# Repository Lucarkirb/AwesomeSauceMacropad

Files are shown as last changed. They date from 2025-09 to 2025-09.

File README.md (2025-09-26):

# AWESOME SAUCE MACROPAD

The best worst macropad I have ever made, for the world to see. 
Runs custom firmware that will support almost infinite layers, macros, and maybe even AHK support?

## What the hell is it?
It's a Seeed studio xiao rp2040 macro pad designed like a madman, with custom firmware thats coming real soon. 
The layout is a 3x3 + an extra 3 button thumb cluster that lets you add more common keys like layer shifters or modifiers. It also has an encoder that can work as what you want but also allows you to interact with the firmwares settings, along with an OLED display to do your bidding.

Currently, the project is a mess as the thing requires the KY-040 encoder breakout board instead of just an smt encoder and also requires a generic i2c oled screen you get for your arduinos.

 

## Can I get it? 
Go order it yourself, tho pcba is going to get pricy since the neo pixels are costly to handle in a factory. Luckily they are super easy to hand solder.

Currently, the project is still being manufactured as im writing this, and thus i dont have any way to write firmware. Stay tuned.

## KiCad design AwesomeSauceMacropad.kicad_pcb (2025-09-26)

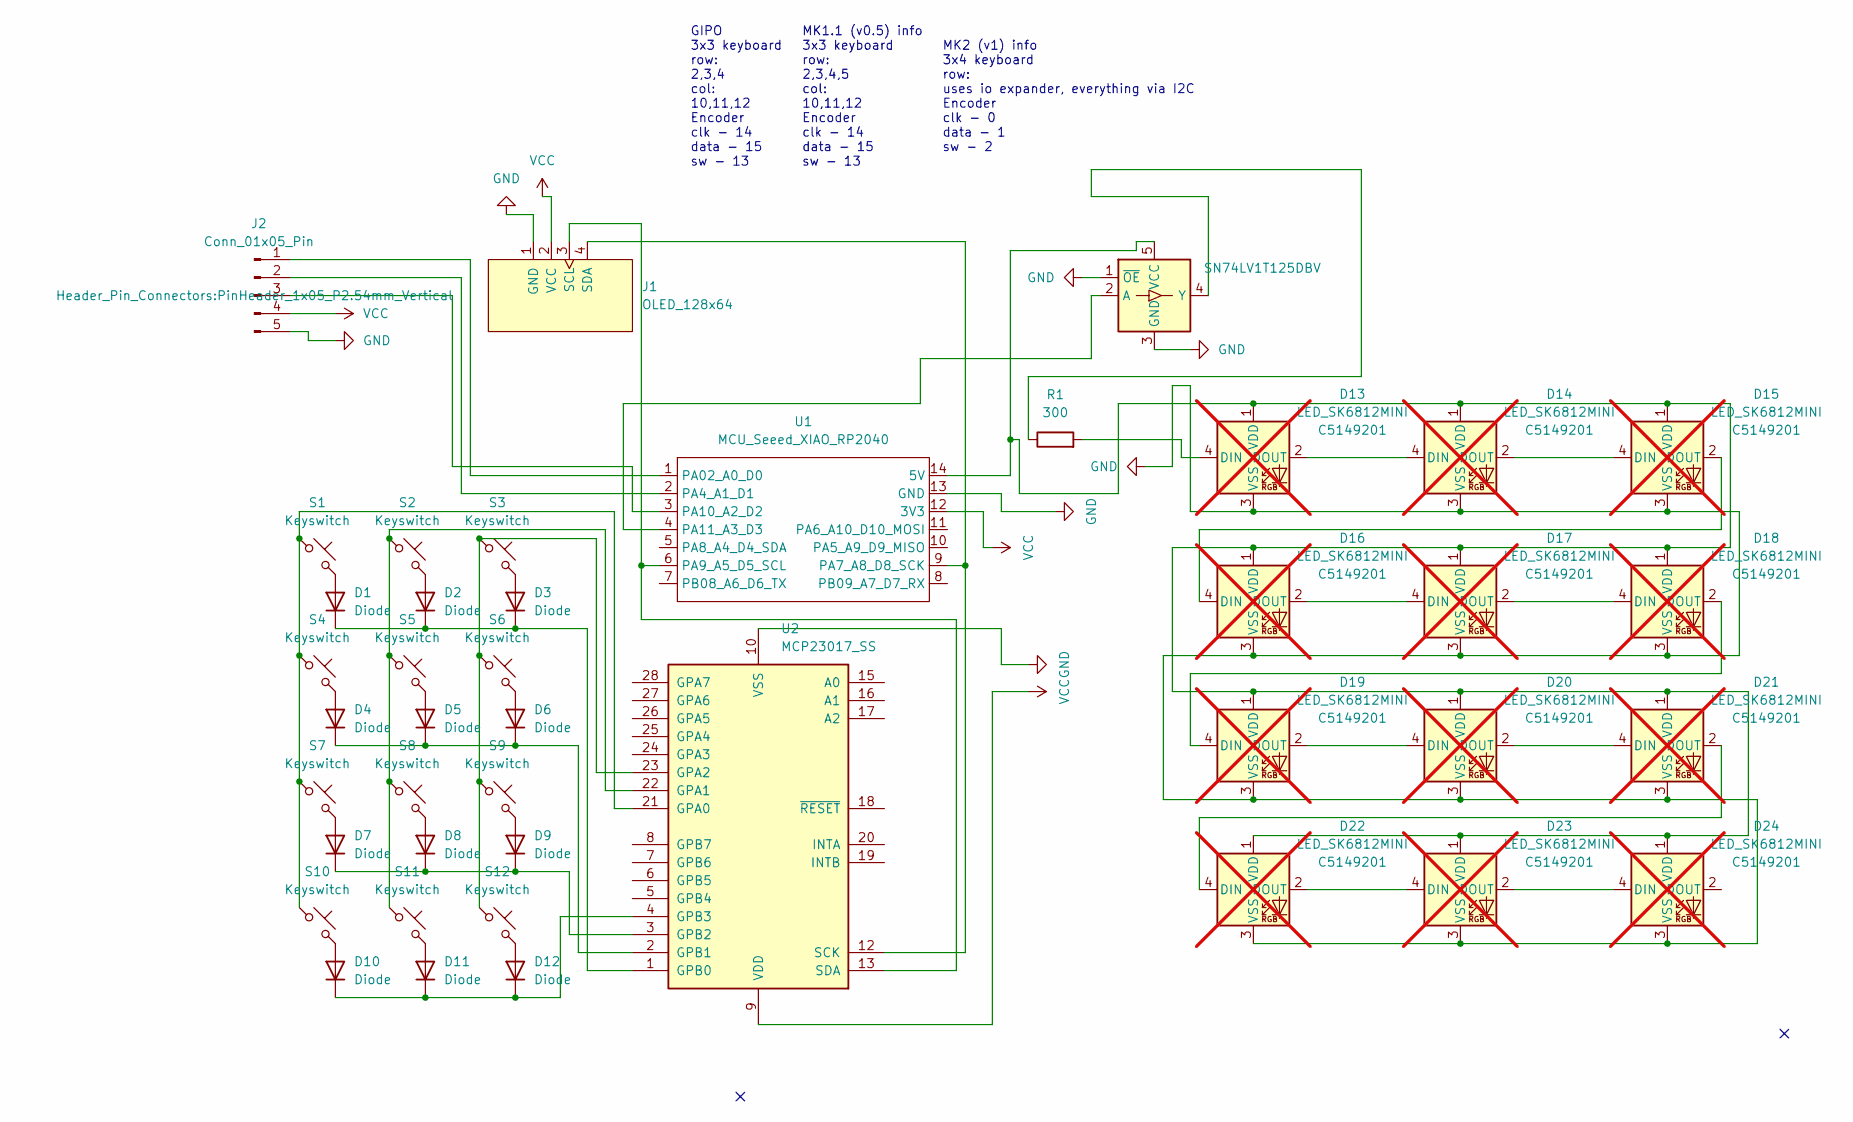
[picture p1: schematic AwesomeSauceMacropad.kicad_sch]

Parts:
D1, D2, D3, D4, D5, D6, D7, D8, D9, D10, D11, D12: Diode; Diode_SOD-123
D13, D14, D15, D16, D17, D18, D19, D20, D21, D22, D23, D24: LED_SK6812MINI; LCSC C5149201; not fitted
J1: OLED_128x64
J2: Conn_01x05_Pin; PinHeader_1x05_P2.54mm_Vertical
R1: 300; Resistor_0805
S1, S2, S3, S4, S5, S6, S7, S8, S9, S10, S11, S12: Keyswitch; Hotswap_Choc_V1V2_1.00u
U1: MCU_Seeed_XIAO_RP2040; Seeed_XIAO_RP2040
U2: MCP23017_SS; SSOP-28_5.3x10.2mm_P0.65mm
U3: SN74LV1T125DBV; SOT-23-5

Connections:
GND: D13.3 (VSS), D14.3 (VSS), D15.3 (VSS), D16.3 (VSS), D17.3 (VSS), D18.3 (VSS), D19.3 (VSS), D20.3 (VSS), D21.3 (VSS), D22.3 (VSS), D23.3 (VSS), D24.3 (VSS), J1.1 (GND), J2.5, U1.13 (GND), U2.10 (VSS), U3.1 (~OE), U3.3 (GND)
unnamed: D1.2 (A), S1.2
unnamed: D1.1 (K), D2.1 (K), D3.1 (K), U2.1 (GPB0)
unnamed: D2.2 (A), S2.2
unnamed: D3.2 (A), S3.2
unnamed: D4.2 (A), S4.2
unnamed: D4.1 (K), D5.1 (K), D6.1 (K), U2.2 (GPB1)
unnamed: D5.2 (A), S5.2
unnamed: D6.2 (A), S6.2
unnamed: D7.2 (A), S7.2
unnamed: D7.1 (K), D8.1 (K), D9.1 (K), U2.3 (GPB2)
unnamed: D8.2 (A), S8.2
unnamed: D9.2 (A), S9.2
unnamed: D10.2 (A), S10.2
unnamed: D10.1 (K), D11.1 (K), D12.1 (K), U2.4 (GPB3)
unnamed: D11.2 (A), S11.2
unnamed: D12.2 (A), S12.2
unnamed: D13.4 (DIN), R1.2
unnamed: D13.2 (DOUT), D14.4 (DIN)
unnamed: D13.1 (VDD), D14.1 (VDD), D15.1 (VDD), D16.1 (VDD), D17.1 (VDD), D18.1 (VDD), D19.1 (VDD), D20.1 (VDD), D21.1 (VDD), D22.1 (VDD), D23.1 (VDD), D24.1 (VDD), U1.14 (5V), U3.5 (VCC)
unnamed: D14.2 (DOUT), D15.4 (DIN)
unnamed: D15.2 (DOUT), D16.4 (DIN)
unnamed: D16.2 (DOUT), D17.4 (DIN)
unnamed: D17.2 (DOUT), D18.4 (DIN)
unnamed: D18.2 (DOUT), D19.4 (DIN)
unnamed: D19.2 (DOUT), D20.4 (DIN)
unnamed: D20.2 (DOUT), D21.4 (DIN)
unnamed: D21.2 (DOUT), D22.4 (DIN)
unnamed: D22.2 (DOUT), D23.4 (DIN)
unnamed: D23.2 (DOUT), D24.4 (DIN)
unnamed: J1.3 (SCL), U1.6 (PA9_A5_D5_SCL), U2.13 (SDA)
unnamed: J1.4 (SDA), U1.9 (PA7_A8_D8_SCK), U2.12 (SCK)
unnamed: J2.1, U1.1 (PA02_A0_D0)
unnamed: J2.2, U1.2 (PA4_A1_D1)
unnamed: J2.3, U1.3 (PA10_A2_D2)
unnamed: U1.4 (PA11_A3_D3), U3.2 (A)
unnamed: S1.1, S4.1, S7.1, S10.1, U2.21 (GPA0)
unnamed: S2.1, S5.1, S8.1, S11.1, U2.22 (GPA1)
unnamed: S3.1, S6.1, S9.1, S12.1, U2.23 (GPA2)
unnamed: R1.1, U3.4 (Y)
VCC: J1.2 (VCC), J2.4, U1.12 (3V3), U2.9 (VDD)

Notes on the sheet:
MK2 (v1) info 3x4 keyboard row: uses io expander, everything via I2C Encoder clk - 0 data - 1 sw - 2
GIPO 3x3 keyboard row: 2,3,4 col: 10,11,12 Encoder clk - 14 data - 15 sw - 13
MK1.1 (v0.5) info 3x3 keyboard row: 2,3,4,5 col: 10,11,12 Encoder clk - 14 data - 15 sw - 13

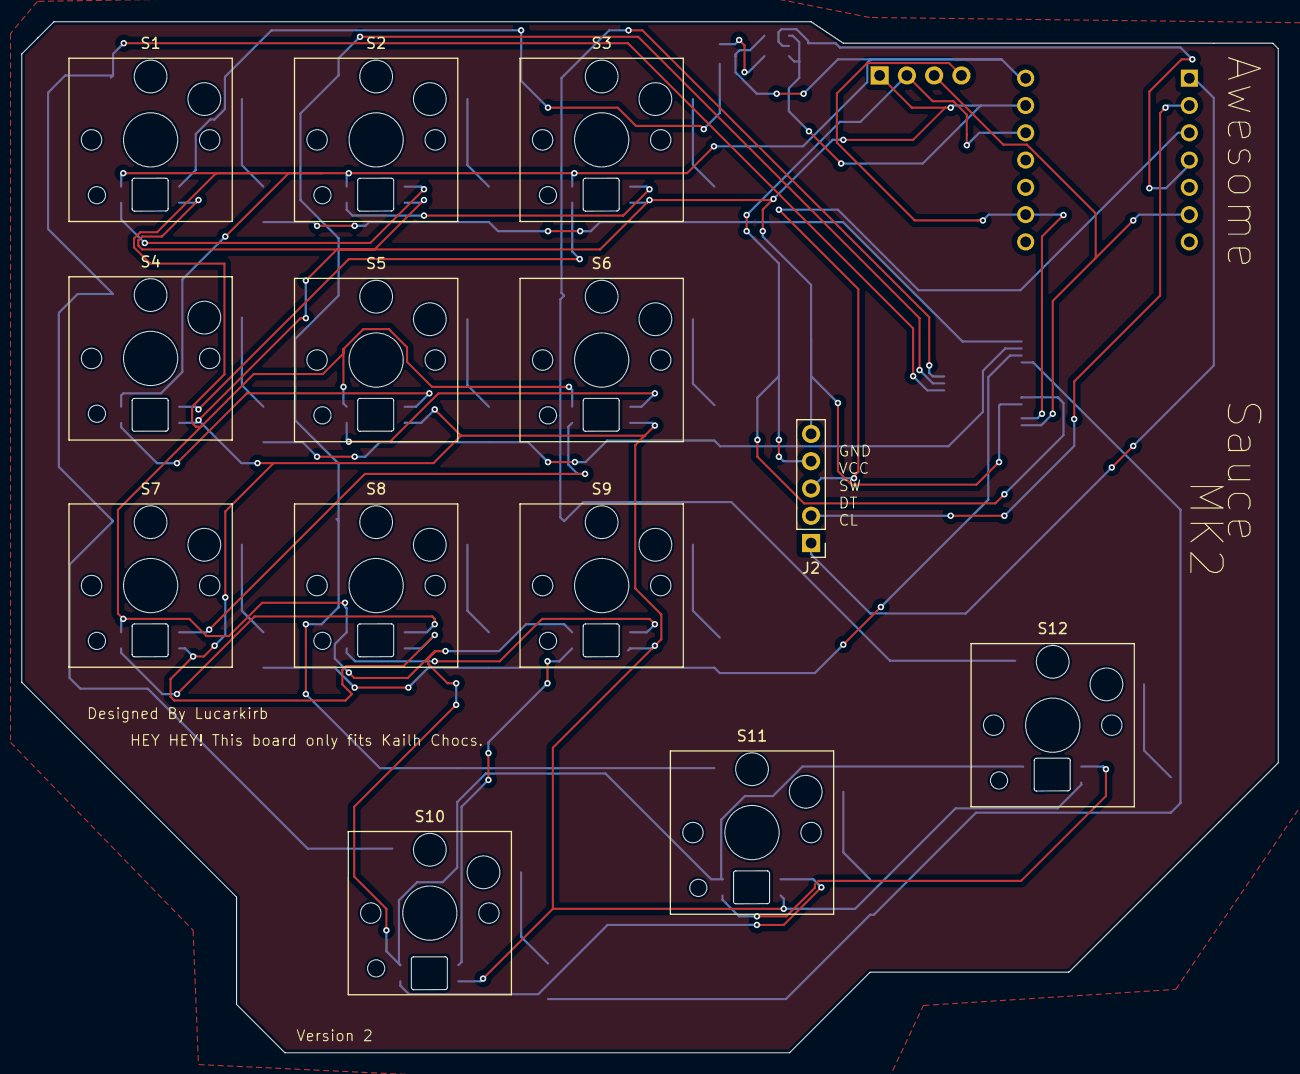
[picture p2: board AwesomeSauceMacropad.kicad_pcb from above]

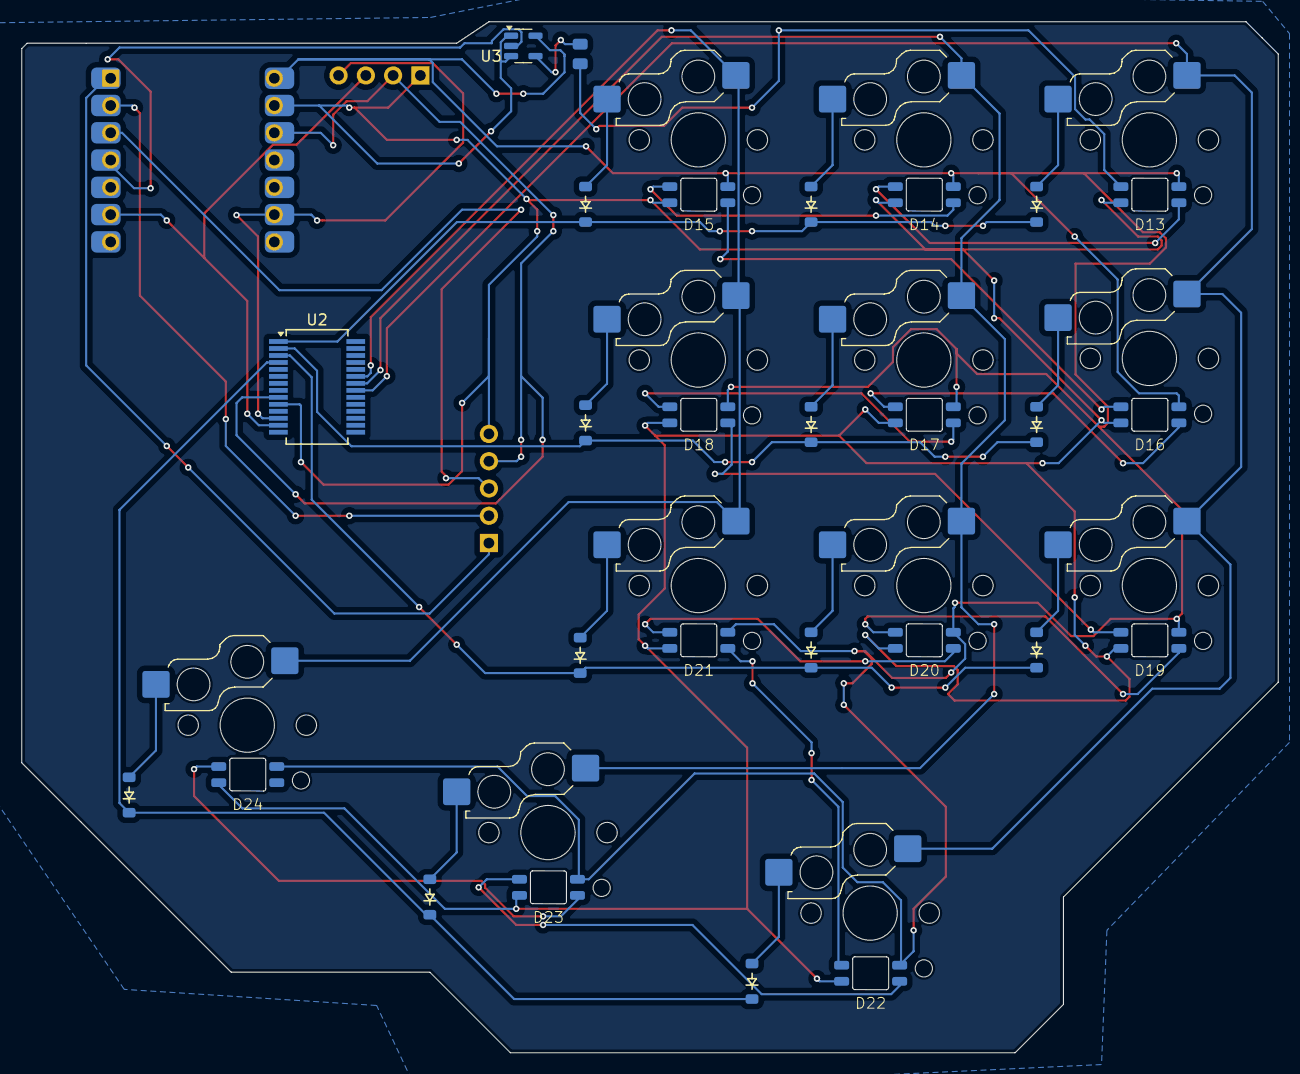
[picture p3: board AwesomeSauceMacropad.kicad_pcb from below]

Board: 2 copper layers, 117.0 x 96.0 mm, 42 parts (28 on the bottom side), 41 nets.

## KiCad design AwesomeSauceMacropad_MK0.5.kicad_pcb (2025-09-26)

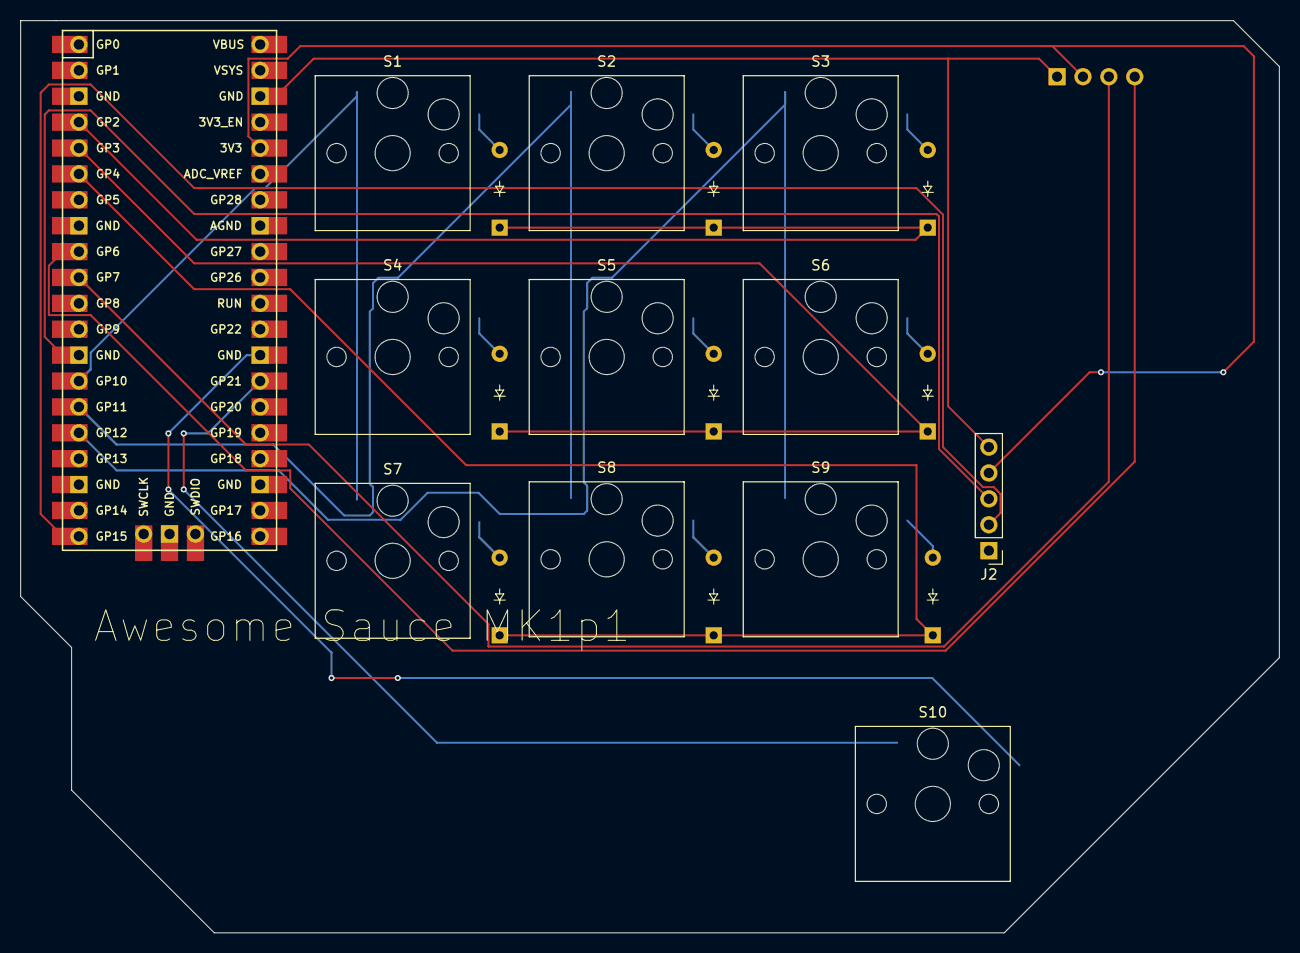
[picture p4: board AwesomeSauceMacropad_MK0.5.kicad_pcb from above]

Board: 2 copper layers, 123.5 x 89.5 mm, 22 parts (0 on the bottom side), 24 nets.

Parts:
D1, D2, D3, D4, D5, D6, D7, D8, D9: Diode; Diode_DO-35
J1: OLED_128x64
J2: Conn_01x05_Pin; PinHeader_1x05_P2.54mm_Vertical
S1, S2, S3, S4, S5, S6, S7, S8, S9, S10: Keyswitch; Hotswap_Choc_V1_1.00u
U1: Raspberry_Pi_Pico

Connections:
GND: J1.1 (GND), J2.5, U1.38 (GND)
unnamed: D1.2 (A), S1.2
unnamed: D1.1 (K), D2.1 (K), D3.1 (K), U1.4 (GPIO2)
unnamed: D2.2 (A), S2.2
unnamed: D3.2 (A), S3.2
unnamed: D4.2 (A), S4.2
unnamed: D4.1 (K), D5.1 (K), D6.1 (K), U1.5 (GPIO3)
unnamed: D5.2 (A), S5.2
unnamed: D6.2 (A), S6.2
unnamed: D7.2 (A), S7.2
unnamed: D7.1 (K), D8.1 (K), D9.1 (K), U1.6 (GPIO4)
unnamed: D8.2 (A), S8.2
unnamed: D9.2 (A), S9.2
unnamed: J1.3 (SCL), U1.10 (GPIO7)
unnamed: J1.4 (SDA), U1.9 (GPIO6)
unnamed: J2.1, U1.19 (GPIO14)
unnamed: J2.2, U1.20 (GPIO15)
unnamed: J2.3, U1.13 (GND)
unnamed: S10.2, U1.28 (GND)
unnamed: S1.1, S4.1, S7.1, U1.14 (GPIO10)
unnamed: S2.1, S5.1, S8.1, U1.15 (GPIO11)
unnamed: S3.1, S6.1, S9.1, U1.16 (GPIO12)
unnamed: S10.1, U1.27 (GPIO21)
VCC: J1.2 (VCC), J2.4, U1.36 (3V3)
